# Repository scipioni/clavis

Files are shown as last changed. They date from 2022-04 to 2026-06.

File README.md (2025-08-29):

# Clavis: A 36-key Split Keyboard

Clavis is a 5x3 split keyboard with three thumb keys, inspired by the Corne keyboard. It's designed with the perfect number of keys for the [Miryoku](https://github.com/manna-harbour/miryoku) layout.

<div align="center">

| Wireless Version (Robinia Wood) | Wireless Version (Bamboo Wood) |
| :---: | :---: |
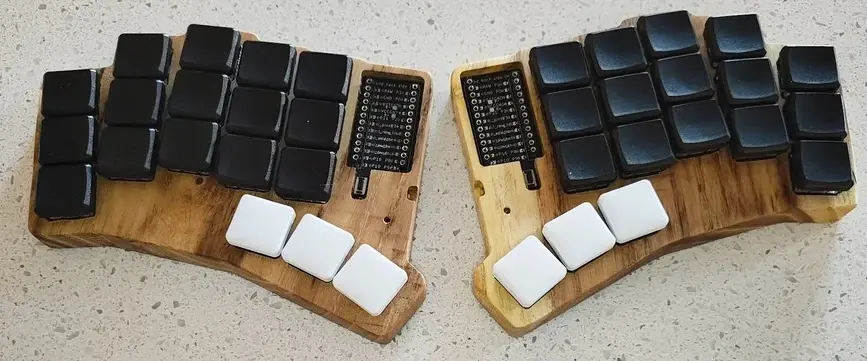
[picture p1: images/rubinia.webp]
Bluetooth with Rubinia wood
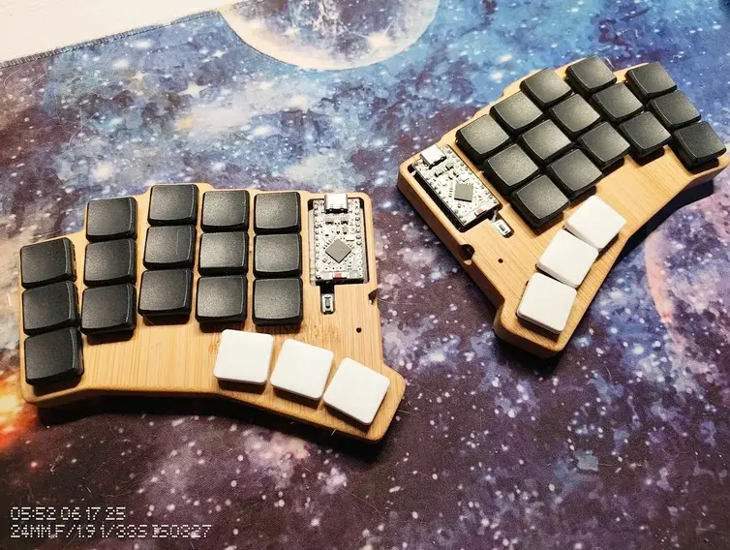
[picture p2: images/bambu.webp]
Bluetooth with Bamboo wood
|  |  |

| Wireless Version | TRRS Version |
| :---: | :---: |
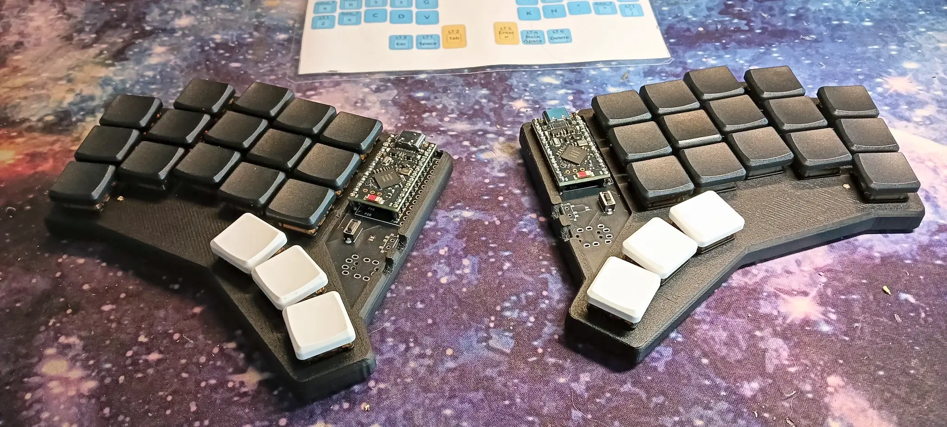
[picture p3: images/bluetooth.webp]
Bluetooth with 3D printed case
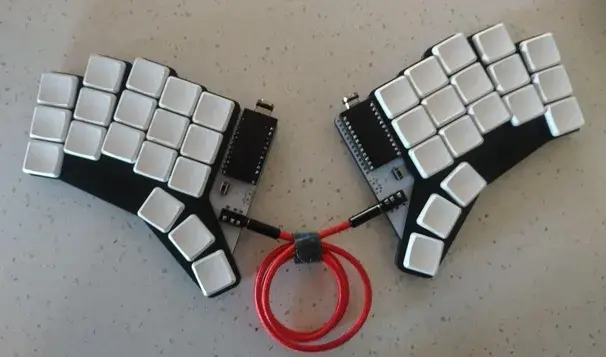
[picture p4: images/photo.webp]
TRRS version
|  |  |

| Wireless Charging | CNC Case |
| :---: | :---: |
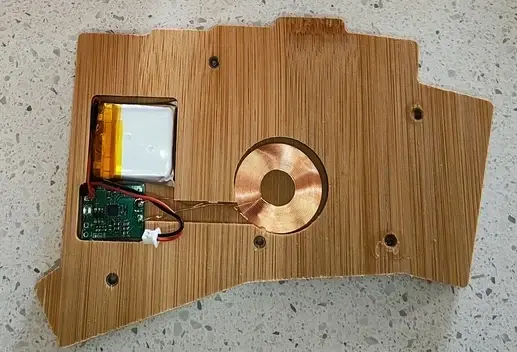
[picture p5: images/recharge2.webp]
Wireless charging
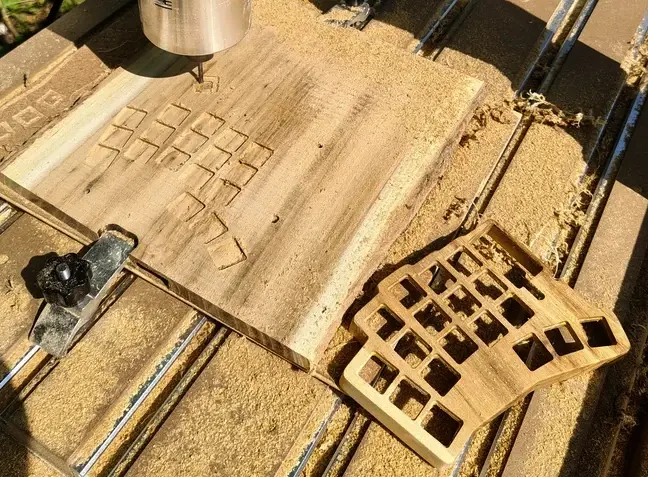
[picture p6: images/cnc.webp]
CNC case
|  |  |

| PCB | STL Model | Miryoku Layout |
| :---: | :---: | :---: |
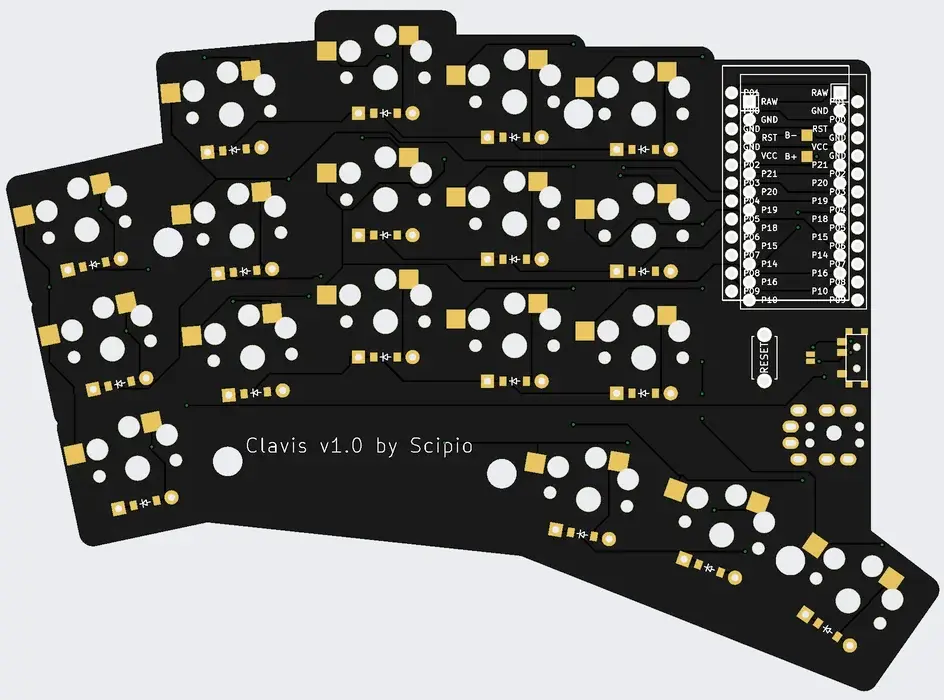
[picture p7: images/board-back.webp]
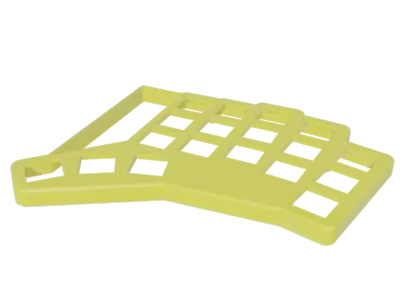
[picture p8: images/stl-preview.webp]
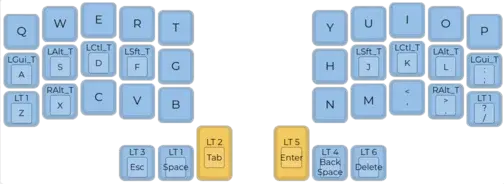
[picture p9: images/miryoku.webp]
Miryoku layout
|  |  |  |

</div>

## Features

*   **Wireless Mode:** Bluetooth connectivity using the nice!nano (ZMK firmware) with wireless charging support.
*   **Wired Mode:** Traditional wired connection via TRRS and USB (QMK firmware).
*   **Declarative Layout:** The keyboard layout is defined using [Ergogen](https://github.com/mrzealot/ergogen/) (using the [soundmonster fork](https://github.com/soundmonster/ergogen.git)).
*   **Automated Workflow:** The build system leverages Ergogen to generate KiCad PCB and plate files from YAML descriptions, suitable for FR-4 fabrication or laser cutting.
*   **Auto-Routing:** Utilizes [freerouting](https://github.com/freerouting/freerouting) to automatically route the PCB traces.
*   **PCB Previews:** Generates PCB previews using [pcbdraw](https://github.com/yaqwsx/pcbdraw).
*   **Production-Ready Gerbers:** Creates production-ready Gerber files with [KiKit](https://github.com/yaqwsx/KiKit).

## Project Components

*   [**PCB**](pcb/README.md): Ergogen-based PCB design and manufacturing files.
*   [**QMK Firmware**](firmware/qmk/README.md): Firmware for wired operation, featuring the [Miryoku layout](firmware/qmk/clavis/README.md).
*   [**ZMK Firmware**](firmware/zmk/README.md): Bluetooth firmware with the [Miryoku layout](firmware/README.md).
*   [**3D Models**](3d/): Blender and STL files for the case.

## Getting Started

1.  **Installation:** Run `make all` to create a Python virtual environment and install the necessary packages.
2.  **Activate Virtual Environment:** `source .venv/bin/activate`
3.  **Build the PCB:** Follow the instructions in the [PCB directory](pcb/).
4.  **Build the Firmware:** Follow the instructions in the [QMK](firmware/qmk/) or [ZMK](firmware/zmk/) directories.
5.  **3D Print the Case:** Check the [3D directory](3d/) for the 3D models.

## References

*   [Keiler Keyboard](https://github.com/jonathanforking/Keiler) and its [firmware](https://github.com/jonathanforking/Keiler-ZMK)
*   [About Sockets](https://github.com/joric/nrfmicro/wiki/Sockets)

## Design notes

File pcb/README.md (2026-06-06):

# Clavis PCB

This document outlines the features, bill of materials, and build process for the Clavis PCB.

## Features

*   **Wireless Ready:** Includes extra pins and a slider switch for a battery, designed for wireless ProMicro clones like the nice!nano. The slider can be shorted with a jumper if using `CONFIG_ZMK_SLEEP` is preferred.
*   **Wired Compatibility:** Supports wired operation with QMK. TRRS footprints are included and routed, with a pinout identical to a five-column Corne (excluding RGB LEDs).
*   **Accessible Reset Switches:** The reset switches are easy to access, using the same footprint as the Corne keyboard.

## Bill of Materials

### Common Components (for both versions)

| Thumbnail | Component | Qty | Description & Source Link |
| :---: | :--- | :---: | :--- |
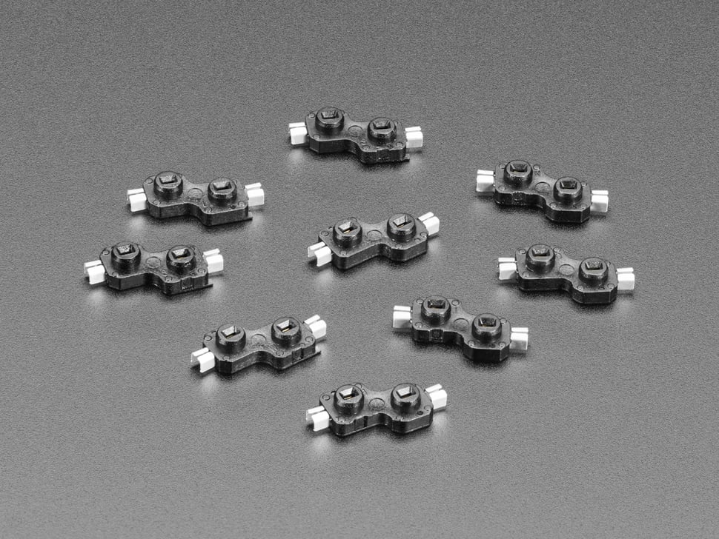
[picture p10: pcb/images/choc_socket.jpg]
Kailh Choc Sockets
|  | **Kailh Choc Sockets** | 36x | [Kailh Choc Low-Profile Hot-Swap Sockets](https://www.aliexpress.com/item/32901654130.html) |
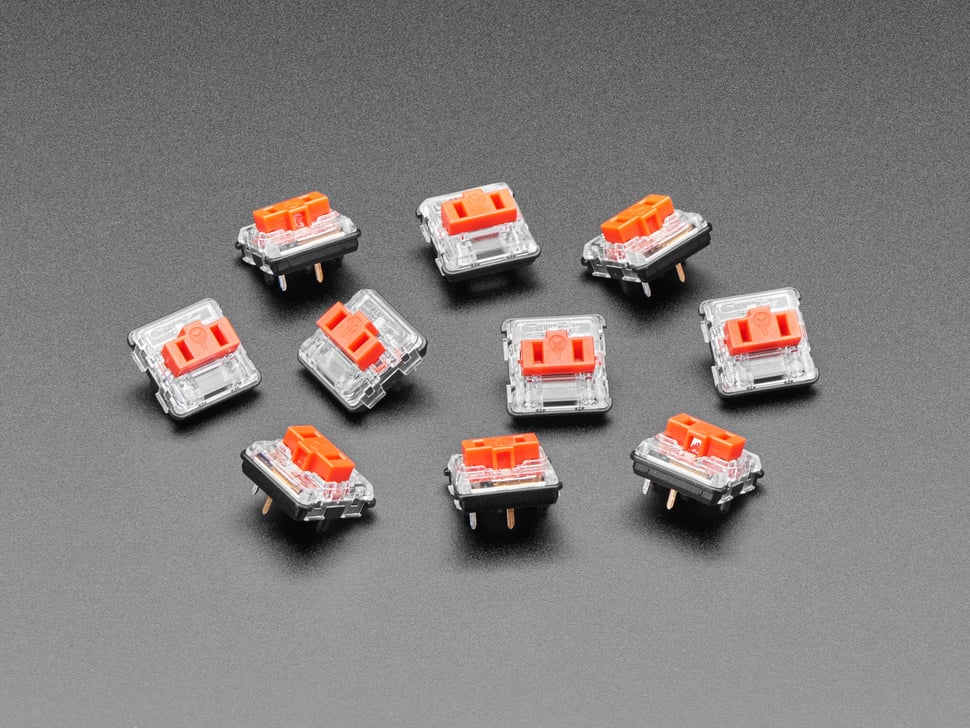
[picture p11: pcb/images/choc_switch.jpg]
Kailh Choc Switches
|  | **Kailh Choc Switches** | 36x | [Kailh Choc Low-Profile Switches](https://it.aliexpress.com/item/1005005446722280.html) |
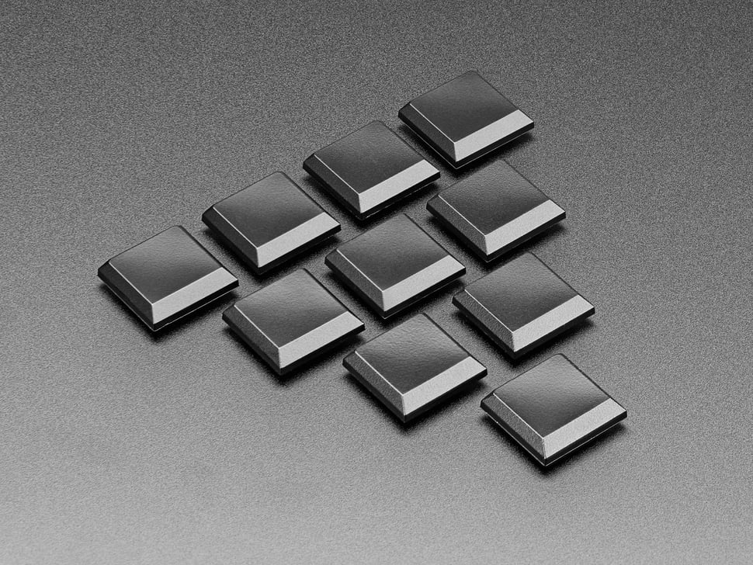
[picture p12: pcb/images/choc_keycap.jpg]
MBK Keycaps
|  | **MBK Choc 1U Keycaps** | 34x | [MBK Choc Low-Profile 1U Keycaps](https://keycapsss.com/keyboard-parts/keycaps/169/mbk-choc-low-profile-blank-keycaps?c=16) |
| MBK Homing Keycaps | **MBK Choc Homing Keycaps** | 2x | [MBK Choc Low-Profile 1U Homing Keycaps](https://keycapsss.com/keyboard-parts/keycaps/169/mbk-choc-low-profile-blank-keycaps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) |
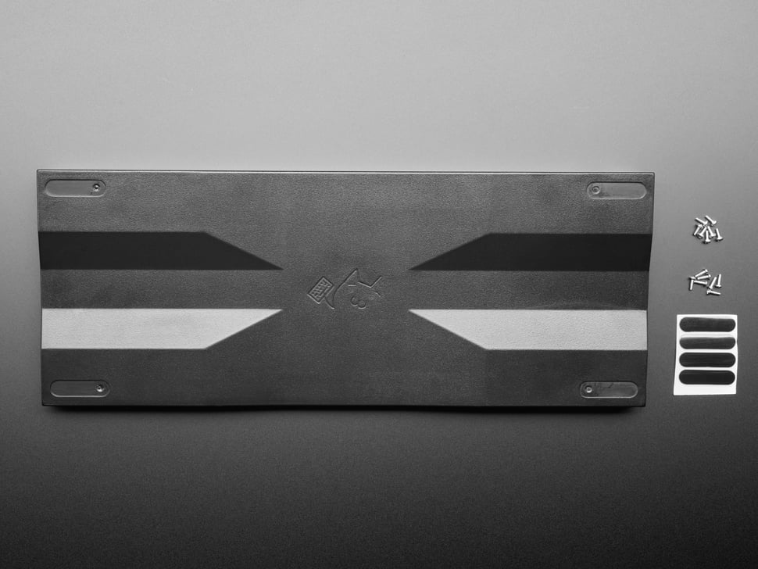
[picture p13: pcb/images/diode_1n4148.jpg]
1N4148 Diodes
|  | **1N4148 SOD-123 Diodes** | 36x | [1N4148 SOD-123 Diodes](https://it.aliexpress.com/item/32849879904.html) |
| Reset Switch | **Micro Switch Buttons** | 2x | [Micro Switch Push Buttons](https://it.aliexpress.com/item/1005007308472247.html) |

### TRRS Version Components

| Thumbnail | Component | Qty | Description & Source Link |
| :---: | :--- | :---: | :--- |
| TRRS Cable | **TRRS Audio Cable** | 1x | [TRRS Audio Cable](https://it.aliexpress.com/item/1005009383566193.html) |
| TRRS Jacks | **TRRS Jacks** | 2x | [TRRS Jacks](https://www.aliexpress.com/item/33029465106.html) |
| Pin Connectors | **Pin Connectors** | - | [Pin Connectors for Microcontroller](https://it.aliexpress.com/item/1005005742644313.html) |
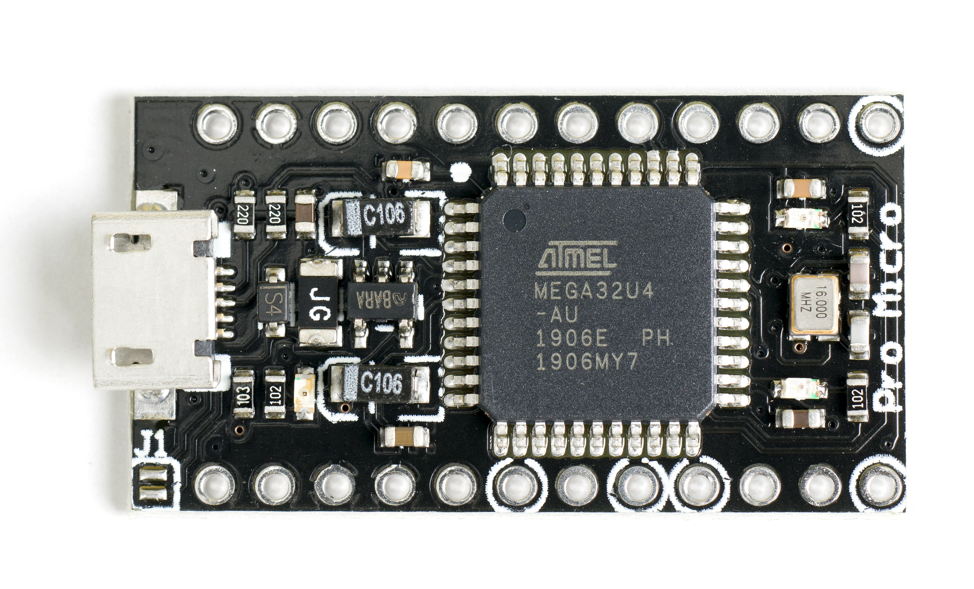
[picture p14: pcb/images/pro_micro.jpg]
Pro Micro
|  | **Pro Micro ATMEGA32U4** | - | [Pro Micro ATMEGA32U4](https://www.aliexpress.com/item/32888212119.html) |

### Bluetooth Version Components

| Thumbnail | Component | Description & Source Link |
| :---: | :--- | :--- |
| Pin Connectors | **Pin Connectors** | [Pin Connectors for Microcontroller](https://it.aliexpress.com/item/1005005742644313.html) |
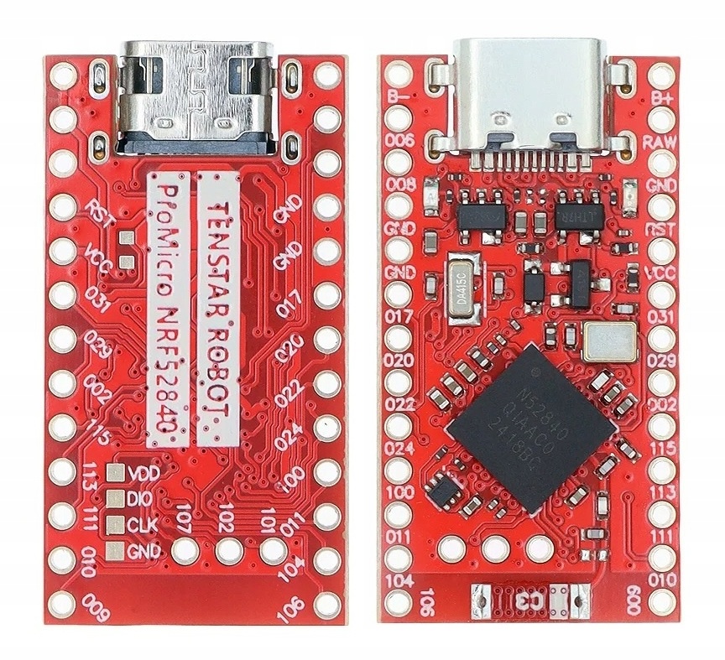
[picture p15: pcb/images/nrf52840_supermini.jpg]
nRF52840 Supermini
|  | **NRF52840 Supermini** | [NRF52840 Supermini (nice!nano V2.0 compatible)](https://www.aliexpress.com/item/1005006343285322.html) |
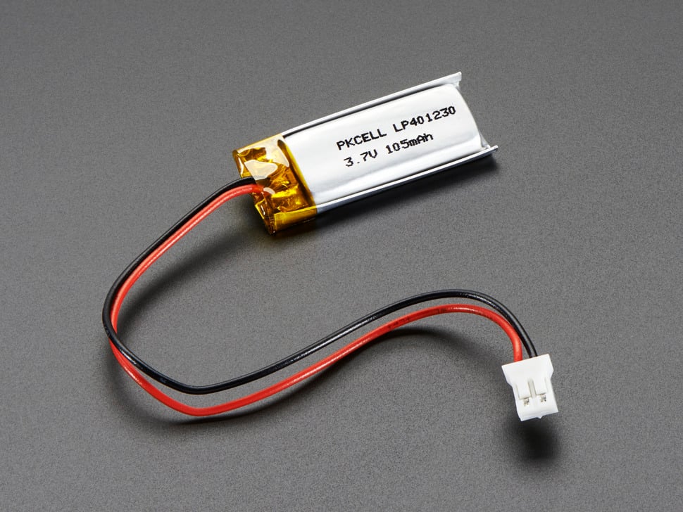
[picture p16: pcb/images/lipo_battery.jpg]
LiPo Battery
|  | **3.7V 140mAh LiPo Battery** | [3.7V 140mAh Lithium Polymer Battery](https://it.aliexpress.com/item/32779771455.html) |

## Build Process

### Prerequisites

*   Node.js
*   KiCad 8
*   Java >= 11 (for freerouting)

### 1. Layout Configuration

Edit `config.yaml` to define your desired layout. You can use the [online Ergogen tool](https://ergogen.cache.works/) to visualize your changes.

### 2. Generate KiCad PCB

This step uses Ergogen to convert your `config.yaml` into KiCad PCB files.

```bash
# Clean previous builds
make clean
# Generate KiCad files
make kicad
```

This will generate the following files in the `output/pcbs/` directory:
* `board.kicad_pcb`
* `bottom_plate.kicad_pcb`
* `top_plate.kicad_pcb`

You can open the PCB in KiCad to inspect it:
```bash
pcbnew output/pcbs/board.kicad_pcb
```

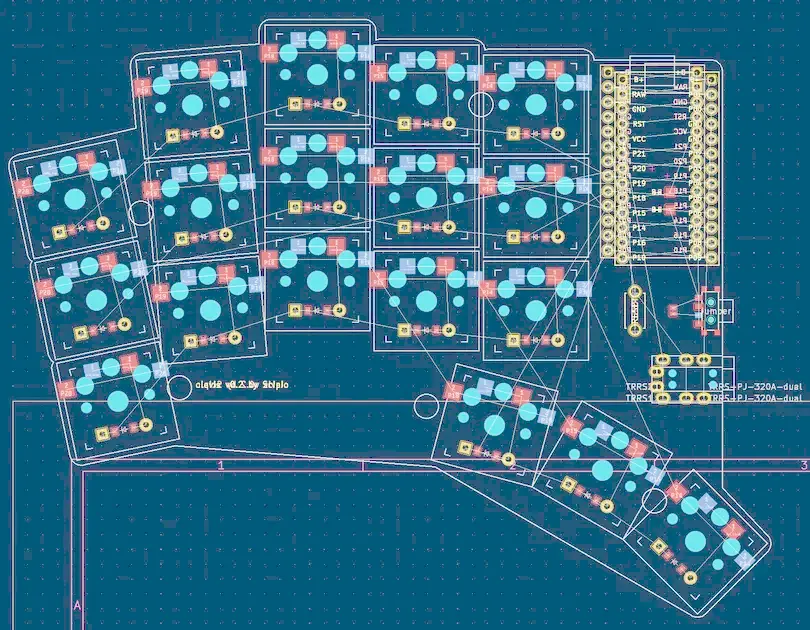
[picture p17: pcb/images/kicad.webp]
KiCad


### 3. Routing

You can choose one of the following methods to route the PCB traces.

#### Method A: EasyEDA Routing

1.  **Export to EasyEDA:** Zip the `output` directory.
2.  **Import to EasyEDA:** In EasyEDA, go to `File -> Open -> KiCad` and upload the zip file.

#### Method B: Freerouting

1.  **Export to Specctra DSN:**
    *   **GUI:** In KiCad, open the board and go to `File -> Export... -> Specctra DSN`.
    *   **CLI:**
        ```bash
        make output/pcbs/board.dsn
        ```

2.  **Autoroute with Freerouting:**
    *   Set the autorouter algorithm to "slow" (in Freerouting 2.0.1, this can only be done via the GUI).
    *   Run the autorouter:
        ```bash
        export PATH="/usr/lib/jvm/java-23-openjdk/bin/:$PATH"
        make output/routed_pcbs/board.ses
        ```
    *   If the process seems to be stuck in a loop, click with the left mouse button.

3.  **Import Routed Session into KiCad:**
    *   **GUI:**
        1.  Open the unrouted PCB: `pcbnew output/pcbs/board.kicad_pcb`
        2.  Import the routed session: `Import -> Specctra session` and select `output/routed_pcbs/board.ses`.
        3.  Run the Design Rule Checker: `Inspect -> Design Rule Checker`.
        4.  Save the routed PCB to `output/routed_pcbs/board.kicad_pcb`.
    *   **CLI:** (TODO)

### 4. Generate Gerbers

This step uses KiKit to create the Gerber files for manufacturing.

```bash
make gerbers-board
```

This will create a `gerbers.zip` file in `output/gerbers/board/`. You can upload this file to a PCB manufacturer like [JLCPCB](https://jlcpcb.com/).

### 5. Create a Release

```bash
git tag -a v1.2 -m "version 1.2"
zip -qr /tmp/clavis-1.2.zip output
```

## Miscellaneous

### DXF to SVG Conversion

You can use an online tool like [Convertio](https://convertio.co/) to convert DXF files to SVG.

### Building Freerouting from Source

1.  Install OpenJDK 21.
2.  Clone the repository and build the executable:
    ```bash
    export PATH="/usr/lib/jvm/java-21-openjdk/bin/:$PATH"
    git clone --depth 1 https://github.com/freerouting/freerouting.git
    cd freerouting
    ./gradlew assemble
    cp build/libs/freerouting-executable.jar ../bin/freerouting-executable.jar
    ```

## TODO

*   Implement a script to import the Specctra session (`scripts/import_ses.py`).
*   Fix the `pcbdraw` rendering of `images/board-front.png`.

## References

*   [Ergogen Part 4: Footprints & Cases](https://flatfootfox.com/ergogen-part4-footprints-cases/)
*   [Ergogen Official Documentation](https://docs.ergogen.xyz/)
*   [Ergogen GitHub Repository](https://github.com/ergogen/ergogen)

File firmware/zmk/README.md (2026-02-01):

# Clavis ZMK Firmware

This document provides instructions for building the ZMK firmware for the Clavis keyboard.

The keyboard layout is defined in the parent directory (`../`) using the Miryoku Babel format.

## Customizing Parameters

The firmware allows customization of various parameters to suit your typing preferences. To customize these parameters, edit the `config/custom_config.h` file.

### U_TAPPING_TERM

The `U_TAPPING_TERM` (zmk tapping-term-ms) parameter controls the time window (in milliseconds) within which a key must be released to register as a tap rather than a hold. This affects all hold-tap behaviors such as:

- Mod-taps (e.g., `&mt` for modifier + key combinations)
- Layer-taps (e.g., `&lt` for switching to a layer when held, sending a key when tapped)
- Other hold-tap behaviors in the layout

The default value is 200ms. A lower value (e.g., 150ms) makes it easier to register taps but requires more precise timing to activate the hold function. A higher value gives more time to decide between tap and hold but can introduce slight delays in hold activation.

Current value: 150ms (overridden in `config/custom_config.h`)

### CONFIG_ZMK_KEYBOARD_NAME

The `CONFIG_ZMK_KEYBOARD_NAME` parameter sets the Bluetooth name of the device. This is the name that appears when pairing the keyboard via Bluetooth.

To customize it, edit the value in `config/corne.conf`.

Current value: "clavis"

## Building the Firmware

To build the firmware, run the following command:

```bash
make
```

## Output

The build process will generate the following files in the `firmware/` directory:

*   `clavis_left.uf2`: Firmware for the left half of the keyboard.
*   `clavis_right.uf2`: Firmware for the right half of the keyboard.
*   `settings_reset.uf2`: Firmware to reset the keyboard's settings.

## Bluetooth pairing

on keyboard reset bluetooth profile (0,1,2,3), for examble 0:
- press and hold U_MEDIA (thumb on left), then SHIFT and hold (j key) and then u_bt_sel_0 (h key)

on linux
```
bluetootctl

# find clavis mac
scan on
devices
--> Device D4:7E:55:3B:A2:96 clavis

# first trust mac, then pair mac
trust D4:7E:55:3B:A2:96
pair D4:7E:55:3B:A2:96

```

now change profile between PC, laptop, phone with:
- press and hold U_MEDIA (thumb on left) and then u_bt_sel_1 (, key) or u_bt_sel_0 (h key)

## Introspection

create keymap from current corne.keymap
```
uv pip install pcpp
pcpp --passthru-unfound-includes config/corne.keymap > /tmp/pcpp.keymap

```

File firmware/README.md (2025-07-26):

# Firmware with Miryoku Layout

This document explains how to generate the Miryoku layout files for various firmware, including ZMK and QMK.

## Generating Miryoku Files

The Miryoku layout is generated from the `miryoku.org` file using Emacs Org Mode.

### Prerequisites

*   **Emacs with Org Mode:** You'll need to have Emacs and Org Mode installed. You can typically install it using your system's package manager:
    ```bash
    # Example for Arch Linux
    yay -S emacs-org-mode
    ```

### 1. Customize the Layout (Optional)

You can edit `miryoku.org` to customize the layout to your preferences.

### 2. Generate Firmware Files

Run the `make` command to generate the firmware files from `miryoku.org`.

```bash
make
```

This will create a `tangled` directory containing the generated files for different firmware types:

```
tangled/
├── kmk/
├── kmonad/
├── qmk/
├── svg/
└── zmk/
```

Each directory will contain the following files:

*   `miryoku_layer_alternatives.h`
*   `miryoku_layer_list.h`
*   `miryoku_layer_selection.h`

### 3. Copy Files to Firmware Directory

After generating the files, copy them to the appropriate firmware directory (e.g., `zmk/miryoku` or `qmk/clavis`).

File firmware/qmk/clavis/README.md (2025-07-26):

# Clavis QMK Layout

This directory contains the QMK keymap for the Clavis keyboard, a 36-key Corne-inspired split keyboard.

*   **Minimal Hardware:** Designed for builds without LEDs or OLED displays.
*   **36-Key Miryoku Layout:** The keymap is based on the [Miryoku layout](https://github.com/manna-harbour/miryoku).
*   **PCB Project:** The hardware project can be found at [scipioni/clavis](https://github.com/scipioni/clavis).

---

## Flashing Instructions

*   **Pro Micro:** `sudo make crkbd:clavis:avrdude`
*   **Elite-C:** `sudo make crkbd:clavis:dfu`

---

## Keymap Layers

| Layer 0 (Base) | Layer 1 (Symbols) |
| :---: | :---: |
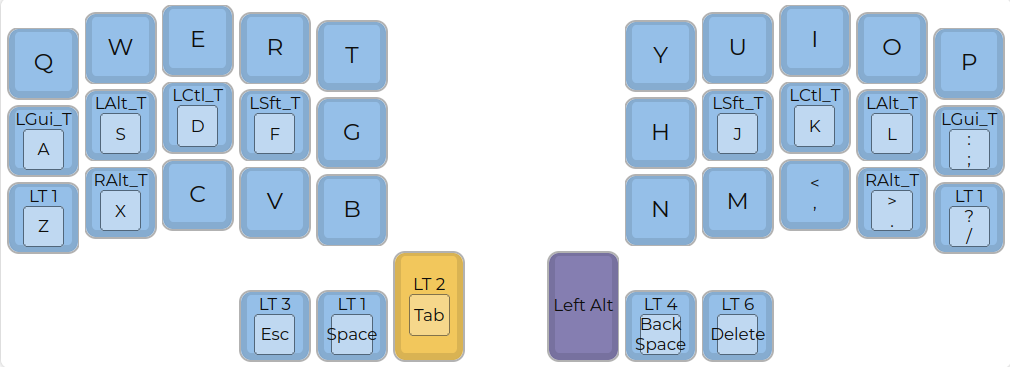
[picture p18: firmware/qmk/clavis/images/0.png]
Layer 0
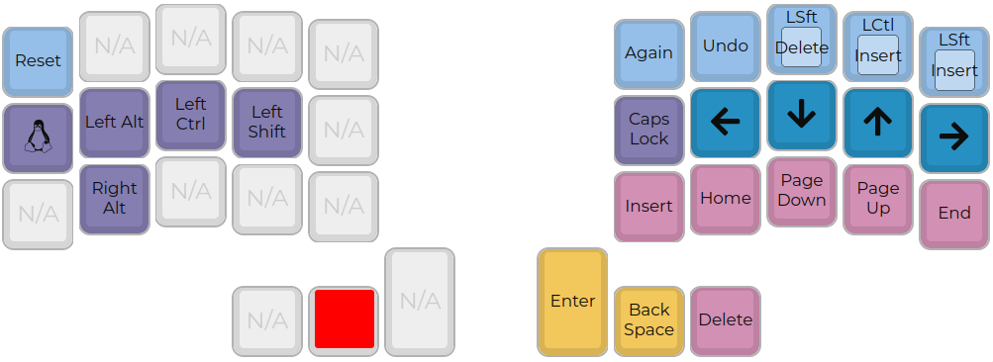
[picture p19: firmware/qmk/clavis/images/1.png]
Layer 1
|  |  |

| Layer 2 (Navigation) | Layer 3 (Mouse) |
| :---: | :---: |
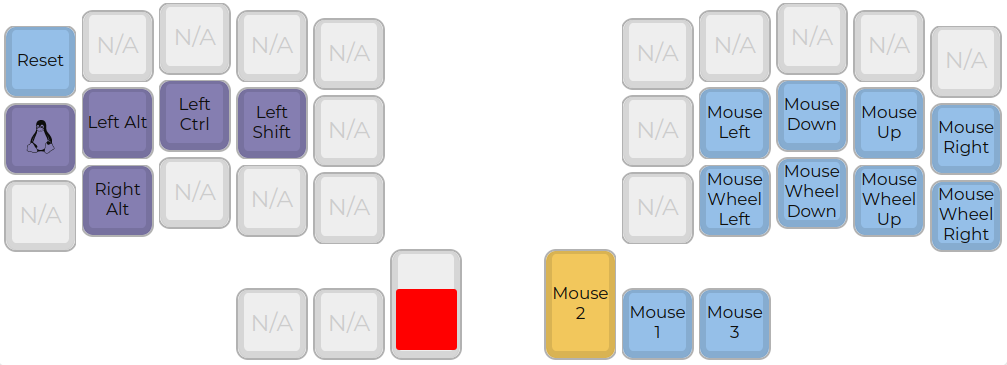
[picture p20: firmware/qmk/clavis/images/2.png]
Layer 2
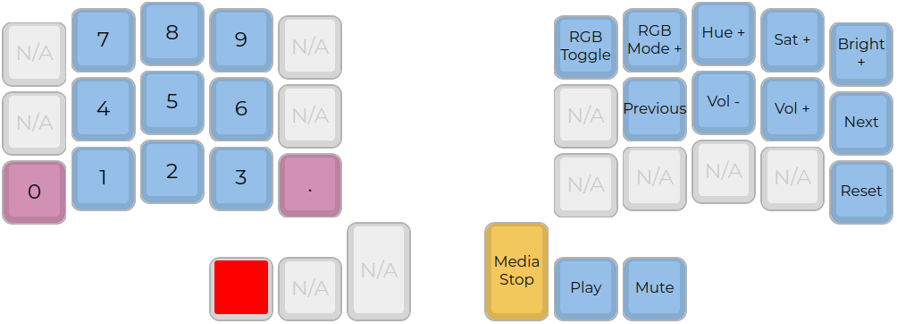
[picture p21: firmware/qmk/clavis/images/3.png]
Layer 3
|  |  |

| Layer 4 (Function Keys) | Layer 5 (Numpad) |
| :---: | :---: |
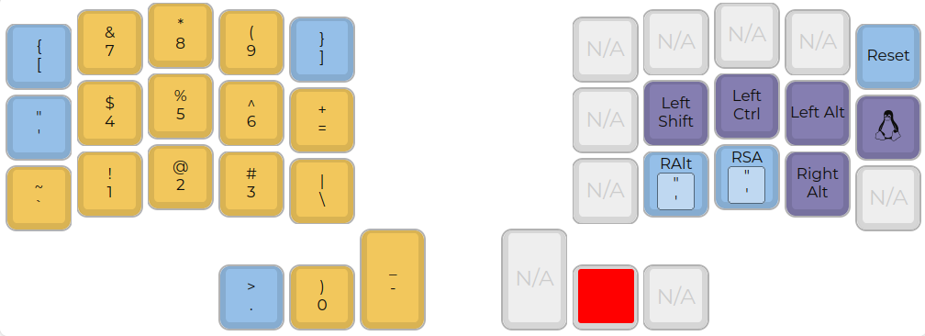
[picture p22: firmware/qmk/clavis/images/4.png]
Layer 4
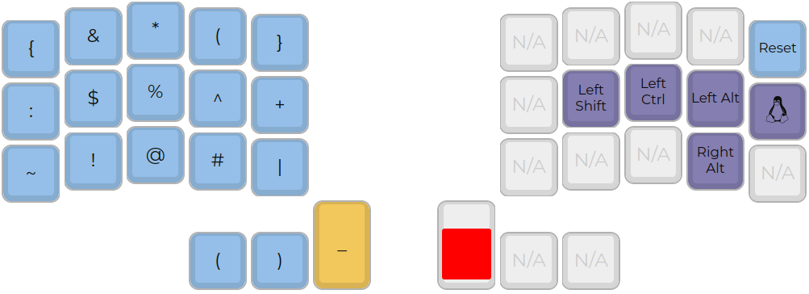
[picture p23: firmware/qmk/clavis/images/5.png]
Layer 5
|  |  |

| Layer 6 (Settings) |
| :---: |
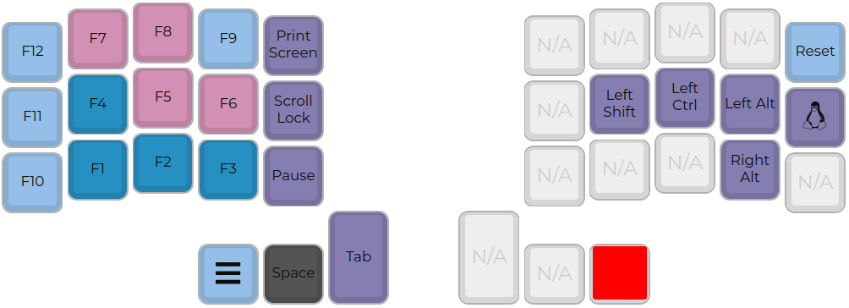
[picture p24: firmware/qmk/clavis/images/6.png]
Layer 6
|  |

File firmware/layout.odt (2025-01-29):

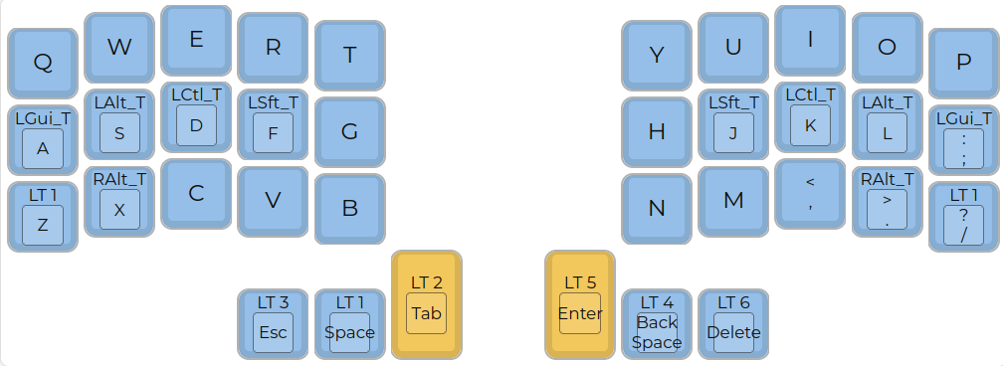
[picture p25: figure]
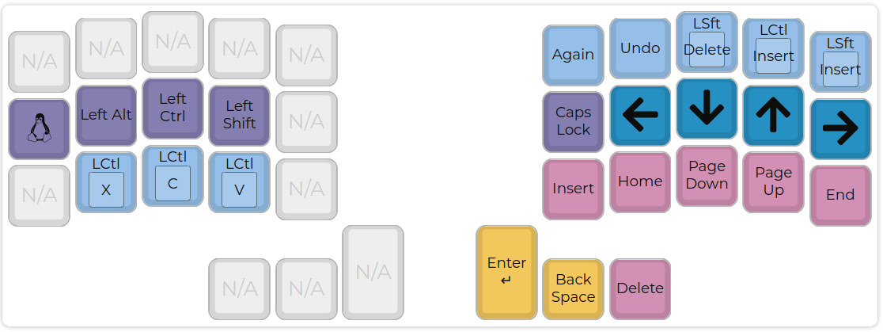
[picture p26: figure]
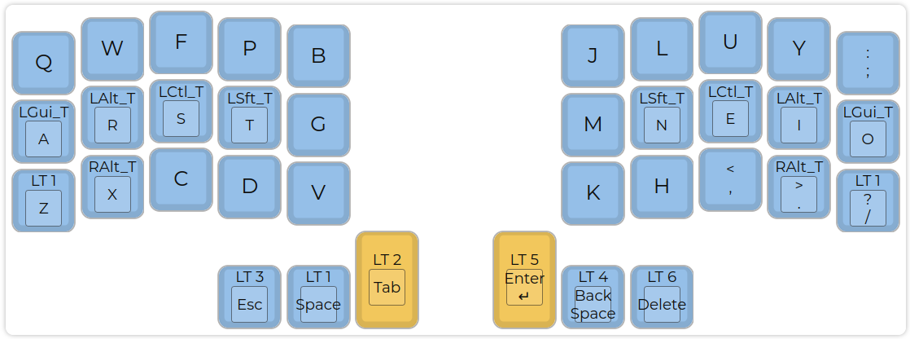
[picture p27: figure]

BT 0

BT 1

BT 2

BT 3

Clavis v0.5

jan-2025

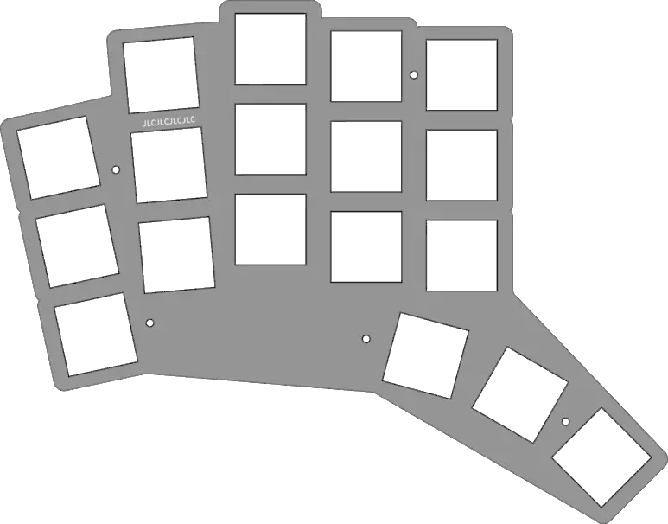
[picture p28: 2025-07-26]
images/board-front.webp

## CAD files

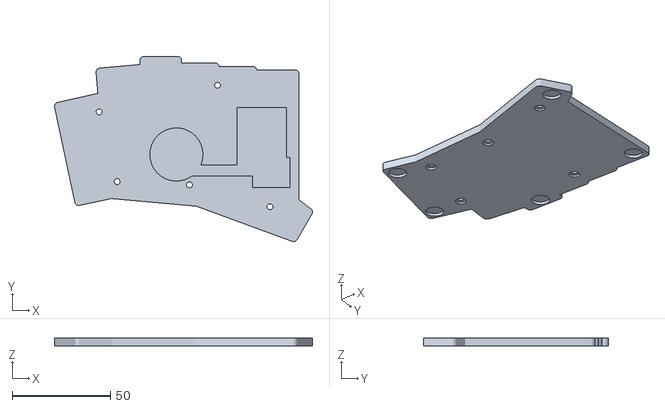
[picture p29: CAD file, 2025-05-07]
3d/clavis-v1-2-bottom.stl
131.1 x 94.1 x 4.00

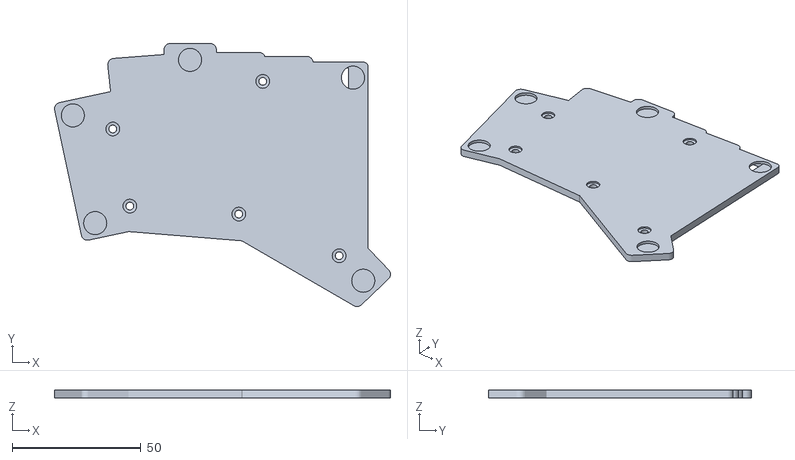
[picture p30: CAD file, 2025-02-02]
3d/clavis-v1-bottom.stl
130.7 x 102.4 x 3.00

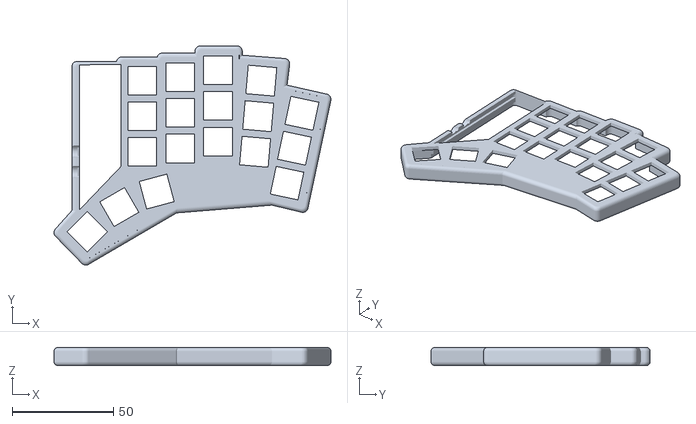
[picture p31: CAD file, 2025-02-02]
3d/clavis-v1-top.stl
137.1 x 108.5 x 9.00

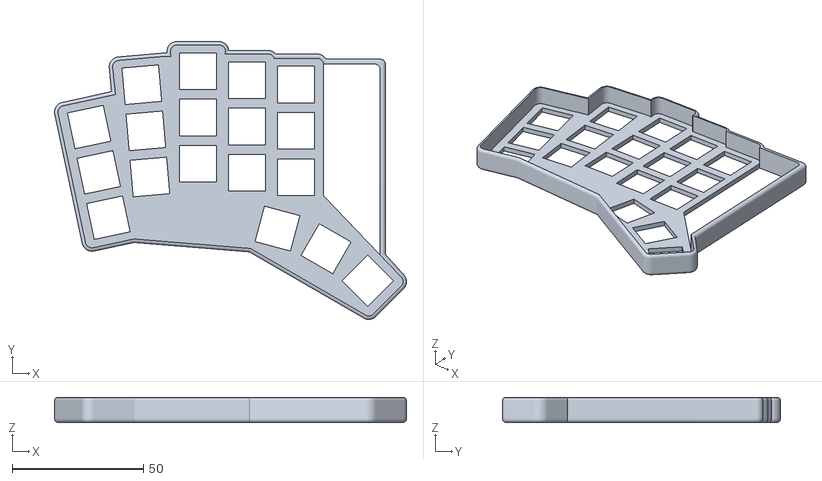
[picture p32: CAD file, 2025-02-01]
3d/clavis.stl
134.3 x 106.1 x 9.55

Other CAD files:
3d/clavis-v1-1-bottom.stl
3d/clavis-v1-1.blend
3d/clavis-v1-2.blend
3d/clavis-v1.blend
3d/clavis.blend
3d/cnc-bottom.blend
3d/cnc-patch.blend
3d/cnc-top-2026.blend
3d/cnc.blend

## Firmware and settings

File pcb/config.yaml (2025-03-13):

meta:
  engine: 4.1.0
  name: clavis
  version: 1.2
  author: Scipio
  url: https://github.com/scipioni/clavis
units:
  kx: cx
  ky: cy
  px: 2
  py: 2
  padding: 1.01
  paddingx: 1.06
points:
  key:
    footprints:
      choc_hotswap:
        type: choc
        params:
          hotswap: true
          reverse: true
          keycaps: true
        nets:
          from: =colrow
          to: =column_net
      diode:
        type: diode
        nets:
          from: =colrow
          to: =row_net
        anchor:
          shift: [0, -5]
  zones:
    matrix:
      key.padding: padding ky
      columns:
        pinky:
          key:
            splay: 12
            stagger: 0 ky
            spread: kx
            column_net: col_pinky
        ring:
          key:
            splay: -7
            stagger: 0.7 ky
            spread: paddingx kx
            column_net: col_ring
        middle:
          key:
            splay: -5
            stagger: 0.2 ky
            spread: paddingx kx
            column_net: col_middle
        index:
          key:
            stagger: -0.2 ky
            spread: paddingx kx
            column_net: col_index
        inner:
          key:
            stagger: -0.1 ky
            spread: paddingx kx
            column_net: col_inner
      rows:
        bottom:
          row_net: row_bottom
        home:
          row_net: row_home
        top:
          row_net: row_top
    thumbfan:
      anchor:
        ref: matrix_inner_bottom
        shift: [-0.5 kx, -1 ky]
      columns:
        near:
          key:
            spread: kx
            splay: -10
            origin: [-0.7 kx, +0.5 ky]
            column_net: col_middle
        home:
          key:
            spread: kx
            splay: -10
            origin: [-0.5 kx, -0.5 ky]
            column_net: col_index
        far:
          key:
            spread: kx
            splay: -10
            origin: [-0.5 kx, -0.5 ky]
            column_net: col_inner
      rows:
        thumb:
          row_net: row_thumb
outlines:
  # board dimensions according to JLCPCB: 122.28 mm x 101.05 mm
  raw:
    - what: rectangle
      where: true
      asym: source
      size: [kx + px + paddingx, ky + py ]
      corner: px
  thumbfan_glue:
    - what: polygon
      points:
        - ref: matrix_inner_bottom
          shift: [0.5 kx + 0.5px, -0.5 ky + 0.5 py]
        - ref: thumbfan_far_thumb
          shift: [0.54 kx - 0.5px, 0.5 ky + 0.5 py]
        - ref: thumbfan_far_thumb
          shift: [0.54 kx - 0.5px, -0.5 ky - 0.5 py]
        - ref: thumbfan_near_thumb
          shift: [-0.5 kx + 0.5 px, -0.5 ky - 0.5 py]
        - ref: matrix_pinky_bottom
          shift: [0.5 kx - 0.5 py, -0.5 ky - 0.5 py]
        - ref: matrix_pinky_home
        - ref: matrix_inner_home
  patch_outer:
    - what: polygon
      points:
        - ref: matrix_ring_top
          shift: [0, -0.1ky]
        - ref: matrix_ring_bottom
        - ref: matrix_pinky_bottom
          shift: [-0.5 (kx + px), 0]
        - ref: matrix_pinky_top
          shift: [-0.3 (kx + px), 0.55ky]
  patch_inner:
    - what: polygon
      points:
        - ref: matrix_ring_top
          shift: [0, 0.50(ky+py)]
        - ref: matrix_ring_bottom
          shift: [0, 0]
        - ref: matrix_middle_bottom
        - ref: matrix_middle_top
          shift: [0, 0.33(ky+py)]
  controller_area:
    - what: rectangle
      where:
        - ref: matrix_inner_top
          # re-tranalte to new anchor position
          shift: [32/2 + 0 kx, 76.5/2 - 4.05 ky]
      size: [32, 76.5]
      corner: px
  switches:
    - what: rectangle
      where: true
      asym: source
      size: 14
  keycaps:
    - what: rectangle 
      where: true
      asym: source
      size: [kx, ky] 
      corner: 1
  keywell:
    - "raw"
    - "+patch_inner"
    - "+patch_outer"
    - "+thumbfan_glue"
  base_outline:
    - "keywell"
    - "+controller_area"
  screw_holes:
    top_left:
      what: circle
      where:
        - ref: matrix_ring_home
          shift: [-0.6 kx, 0.27 ky]
      radius: 1.05
    bottom_left:
      what: circle
      where:
        - ref: matrix_pinky_bottom
          shift: [0.7 kx, -0.1 ky]
      radius: 1.05
    top_right:
      what: circle
      where:
        - ref: matrix_inner_top
          shift: [-0.52 kx, 0]
      radius: 1.05
    palm:
      what: circle
      where:
        - ref: matrix_index_bottom
          shift: [-0.25 kx, -1.06 ky]
      radius: 1.05
    thumb:
      what: circle
      where:
        - ref: thumbfan_far_thumb
          shift: [-0.54 kx, 0]
      radius: 1.05
  mounting_holes:
    $extends: outlines.screw_holes
    top_left:
      radius: 1.7
    bottom_left:
      radius: 1.7
    top_right:
      radius: 1.7
    palm:
      radius: 1.7
    thumb:
      radius: 1.7
    led:
      what: circle
      where:
        - ref: matrix_inner_bottom
          shift: [26.8, -10.6]
      radius: 1.05
  bottom_outline:
    - "base_outline"
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

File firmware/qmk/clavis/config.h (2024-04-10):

// see https://precondition.github.io/home-row-mods#tap-hold-configuration-settings

#pragma once

#undef USE_I2C
#undef SSD1306OLED
#define USE_SERIAL_PD2

#define SPLIT_USB_DETECT
#define SPLIT_USB_TIMEOUT 2000
#define SPLIT_USB_TIMEOUT_POLL 10
#define SPLIT_WATCHDOG_ENABLE

/* Select hand configuration */
#define MASTER_LEFT
//#define MASTER_RIGHT

// sets the keyboard's handedness by setting a flag in the persistent storage (EEPROM)
// make crkbd:clavis:avrdude-split-left
// make crkbd:clavis:avrdude-split-right
//#define EE_HANDS

#define USE_SERIAL_PD2

//#undef TAPPING_TERM
#define TAPPING_TERM 200
#define QUICK_TAP_TERM 0

// Auto Shift
#define NO_AUTO_SHIFT_ALPHA
#define AUTO_SHIFT_TIMEOUT TAPPING_TERM
#define AUTO_SHIFT_NO_SETUP

// Recommended for heavy chording.
#define QMK_KEYS_PER_SCAN 4

// Mouse key speed and acceleration.
#undef MOUSEKEY_DELAY
#define MOUSEKEY_DELAY          0
#undef MOUSEKEY_INTERVAL
#define MOUSEKEY_INTERVAL       16
#undef MOUSEKEY_WHEEL_DELAY
#define MOUSEKEY_WHEEL_DELAY    0
#undef MOUSEKEY_MAX_SPEED
#define MOUSEKEY_MAX_SPEED      6
#undef MOUSEKEY_TIME_TO_MAX
#define MOUSEKEY_TIME_TO_MAX    64

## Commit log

2022-04-19 blender model
    [clavis.blend]
2022-12-31 bill of materials
2023-01-08 - fix docs - printable stl model
    [clavis.blend, clavis.stl]
2023-01-08 fix blender model
    [clavis.blend, clavis.stl]
2025-01-05 feat(3D): border
    [clavis.blend, clavis.stl]
2025-01-09 references to keiler keyboard and sockets
    [clavis.blend, clavis.stl]
2025-01-23 fix 3d: bigger outer edge
    [clavis.blend, clavis.stl]
2025-01-23 fix 3d model
    [clavis.blend, clavis.stl]
2025-01-23 fix 3d: support on pcb beside micro
    [clavis.blend, clavis.stl]
2025-01-27 fix: model 3d
    [clavis.stl]
2025-01-31 feat: model 3D baseline
    [clavis.blend]
2025-02-04 fix holes
    [clavis-v1.blend, clavis.blend]
2025-02-09 docs: wireless
2025-03-04 v1.1 3d model
    [clavis-v1-1-bottom.stl, clavis-v1-1.blend]
2025-03-06 stl models v1.1
    [clavis-v1-1-bottom.stl]
2025-03-06 fix led
    [clavis-v1-1.blend]
2025-03-07 fix model 3D
    [clavis-v1-1.blend]
2025-03-07 fix model 3D normals
    [clavis-v1-1.blend]
2025-03-07 fix 3D model normals
    [clavis-v1-1.blend]
2025-03-07 fix led position
    [clavis-v1-1.blend]
2025-03-14 fix 3d normals
    [clavis-v1-1.blend]
2025-04-19 model 3D: heigth 10mm
    [clavis-v1-1-bottom.stl, clavis-v1-1.blend]
2026-02-01 docs(zmk): add bluetooth pairing guide and update media layer
    Add comprehensive Bluetooth pairing documentation including:
    - Profile reset procedure using keyboard shortcuts
    - Linux pairing steps with bluetoothctl
    - Profile switching between multiple devices
    Replace RGB toggle with LSHIFT key on media layer to support
    Bluetooth pairing key combinations.
2026-06-06 docs(pcb): update bill of materials links and format tables with local thumbnails
    - Convert Bill of Materials lists to beautifully formatted, structured markdown tables for Common, TRRS, and Bluetooth versions.
    - Download all remote component thumbnails locally into the pcb images directory to make documentation completely self-contained and offline-compatible.
    - Replace broken reference link (sloba-byte/ergogen_howtos) with official Ergogen documentation and GitHub repository.
    - Correct 1N4148 diodes link and update microcontroller, switches, audio cable, and pin connectors to correct user-preferred AliExpress links.
    - Use custom local images provided by the user for micro switches, TRR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
    [cnc-top-2026.blend]
2026-08-30 style: format Python helper and automation scripts in pcb and zmk firmware
    Standardize code style and formatting across python scripts:
    - Format firmware/zmk/prettier.py to use standard double quotes, improve dictionary formatting, and remove trailing blank lines.
    - Format pcb/scripts/export_dsn.py to use double quotes and cleaner spacing.
    - Format pcb/scripts/import_ses.py to clean up indentation and trailing whitespaces.
    - Format pcb/scripts/import_ses_soundmonster.py to use double quotes, clean up indentation, and format complex python structures standardly.
